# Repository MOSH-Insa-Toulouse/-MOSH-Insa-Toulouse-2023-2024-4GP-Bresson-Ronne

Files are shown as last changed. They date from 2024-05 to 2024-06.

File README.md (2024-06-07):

# -MOSH-Insa-Toulouse-2023-2024-4GP-Bresson-Ronne

Projet 4GP du capteur au banc de test en open source hardware
---
## Sommaire
  - [1) Contexte](#1-contexte)
  - [2) L'électronique Analogique](#2-L'électroniqueAnalogique)
  - [3) Kicad](#3-kicad)
  - [4) Le code Arduino](#4-lecodeArduino)
  - [5) L'application Bluetooth ](#5-l'appli)
  - [6) La DataSheet ](#6-data)
---

## 1) Contexte
Dans le cadre de l'UE "Du capteur au banc de test en Open Source Hardware", nous avons été amenés à réaliser un capteur de déformation low-tech à base de graphite. Le fonctionnement de ce capteur repose sur la variation de résistance engendrée par la déformation du matériau. La physique sous-jacente à cette variation de résistance provient du déplacement des électrons par effet tunnel entre les nanoparticules de graphite. Lorsqu'une contrainte mécanique est appliquée, la distance entre les nanoparticules varie, ce qui modifie la conductivité du graphite. Cette modification entraîne ainsi une variation de la résistance du capteur.<br>
Ce capteur est ensuite connnecté à un arduino. Divers élements sont ajoutés à l'Arduino, un capeteur flex sensor industriel que l'on comparera à notre capteur LowTech maison, un écran Oled pour pouvoir afficher nos résultats et un encodeur rotatoire qui permet de se déplacer sur les menus de l'écran Oled. Un module bluetooth est aussi implémenté en vue de créer une application android pour visualiser nos données. 

<p align="center">
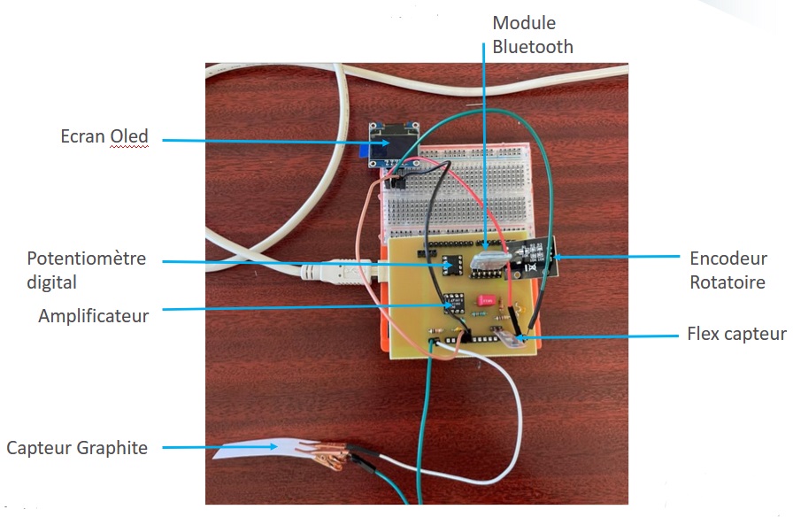
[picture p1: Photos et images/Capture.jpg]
Photo de l'installation
  
  <br>
  <i>Photo de l'installation</i>
</p>

## 2) L'électronique Analogique
Une partie importante de la chaîne d’acquisition pour notre capteur réside dans le
conditionnement du signal délivré par le capteur, c’est-à-dire l’amplifier et le filtrer
pour pouvoir l’exploiter. Afin d’utiliser les capacités de la carte Arduino au maximum
(en pleine échelle), le gain du circuit d’amplification est variable grâce à la résistance
R2, ajustée par un potentiomètre digital.<br>
Le filtrage est effectué à plusieurs niveaux (avant et après amplification). Il y a donc 3
étages, chacun avec une fréquence de coupure différente, pour limiter le bruit au
maximum. Le circuit est modélisé dans LTSpice, afin d’effectuer des simulations. Il
faut noter qu’ici on peut se permettre d’avoir un filtrage fort à des fréquences très
faibles car à priori notre capteur ne sera pas utilisé à plus qu’environ 1Hz. Les
résultats obtenus par les simulations et un exemple de simulation (Diagramme de
Bode pour un étage sont présentés sur les figures suivantes. Le circuit LTSpice est à
trouver dans le dossier « électronique analogique ».

<p align="center">
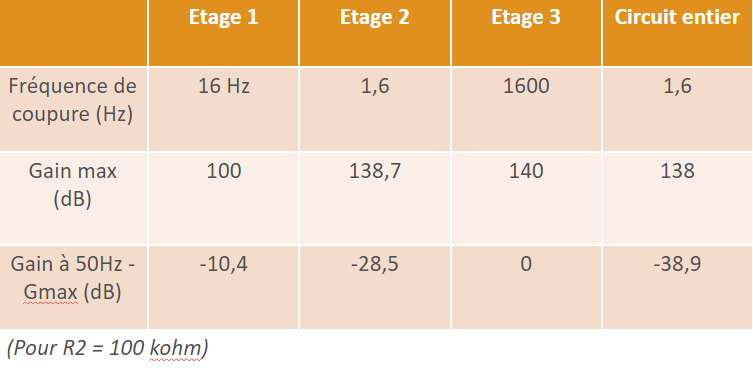
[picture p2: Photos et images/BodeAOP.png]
Caractéristiques de l'AOP
  
  <br>
  <i>Caractéristiques de l'AOP</i>
</p>

<p align="center">
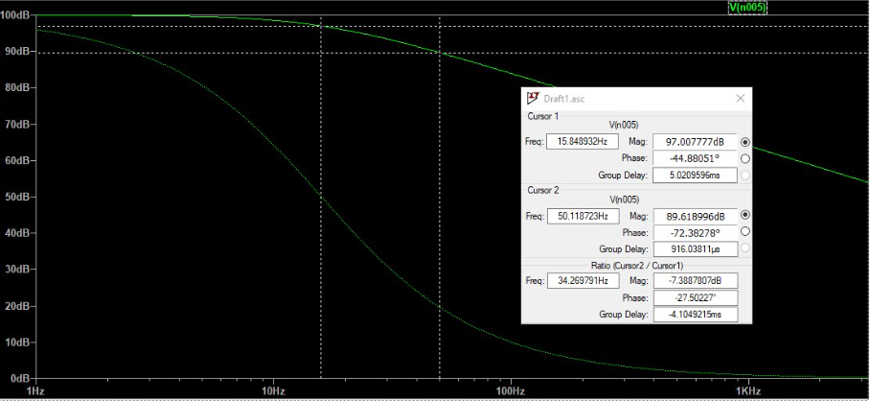
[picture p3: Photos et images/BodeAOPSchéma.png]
Diagramme de Bode du premier étage de l'AOP
  
  <br>
  <i>Diagramme de Bode du premier étage de l'AOP</i>
</p>

## 3) Kicad
Afin de réaliser en pratique le circuit modélisé dans LTSpice, ainsi qu’ajouter tous les
composants liés à notre chaîne d’acquisition et aux capteurs, le logiciel KiCad est
utilisé. Il permet à partir d’un schéma électrique, créé dans un premier temps, et de
l’ajout des empreintes et modèles 3D des différents composants, de modéliser le
PCB et ses pistes électroniques, et d’en obtenir un modèle 3D. Ces documents sont
disponibles dans le dossier « KiCad ». Avec l’aide de Catherine Crouzet, nous avons
ensuite pu fabriquer notre PCB y souder les composants pour tester toute notre
chaîne d’acquisition, qui s’est avérée fonctionnelle directement.

<p align="center">
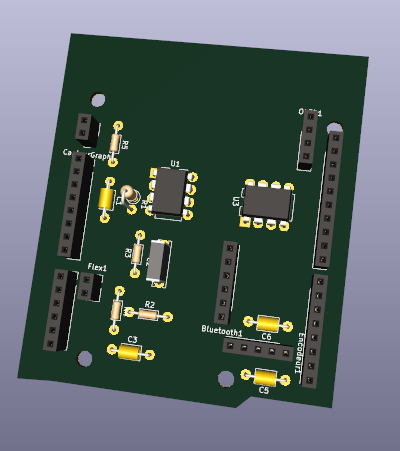
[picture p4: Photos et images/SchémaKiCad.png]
Schéma du PCB réalisé sur KiCad
  
  <br>
  <i>Schéma du PCB réalisé sur KiCad</i>
</p>

## 4) Le code Arduino

Un code Arduino est implémenté sur un ArduinoUno. Le code permet d'afficher les valeurs de résistance sur l'écran oled et de choisir quel capteur est affiché via un encodeur rotatoire. Les valeurs de résitances sont aussi disponibles sur le serialmonitor ainsi que sur le téléphone. 

## 5) Lapplication 
L’application Android, créée avec le MIT App Inventor, permet de dialoguer via Bluetooth
(bouton de connexion à activer) avec la carte Arduino pour obtenir les valeurs de
résistance/angle fournies par le capteur. L’utilisateur peut choisir un nombre de mesures à
effectuer, le moment pour les lancer, puis ces mesures sont affichées en live sur un
indicateur numérique, un graphique, et exportées dans un tableur afin de les exploiter au
mieux. Un fichier APK est téléchargeable dans le dossier « Application Android »

<p align="center">
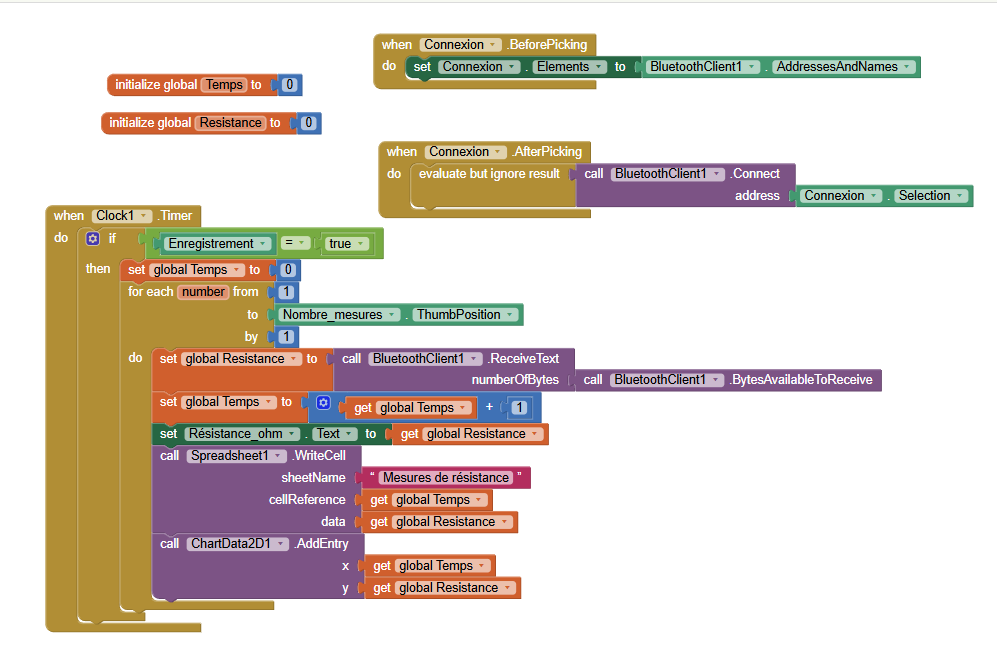
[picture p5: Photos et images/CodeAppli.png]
Schéma de l'application Android
  
  <br>
  <i>Schéma de l'application Android</i>
</p>

## 6) La DataSheet 
La data sheet du capteur est disponible  [ici](https://github.com/MOSH-Insa-Toulouse/2023-2024-4GP-Bresson-Ronne/blob/main/DataSheet/datasheetCapteurBressonRonne.pdf).

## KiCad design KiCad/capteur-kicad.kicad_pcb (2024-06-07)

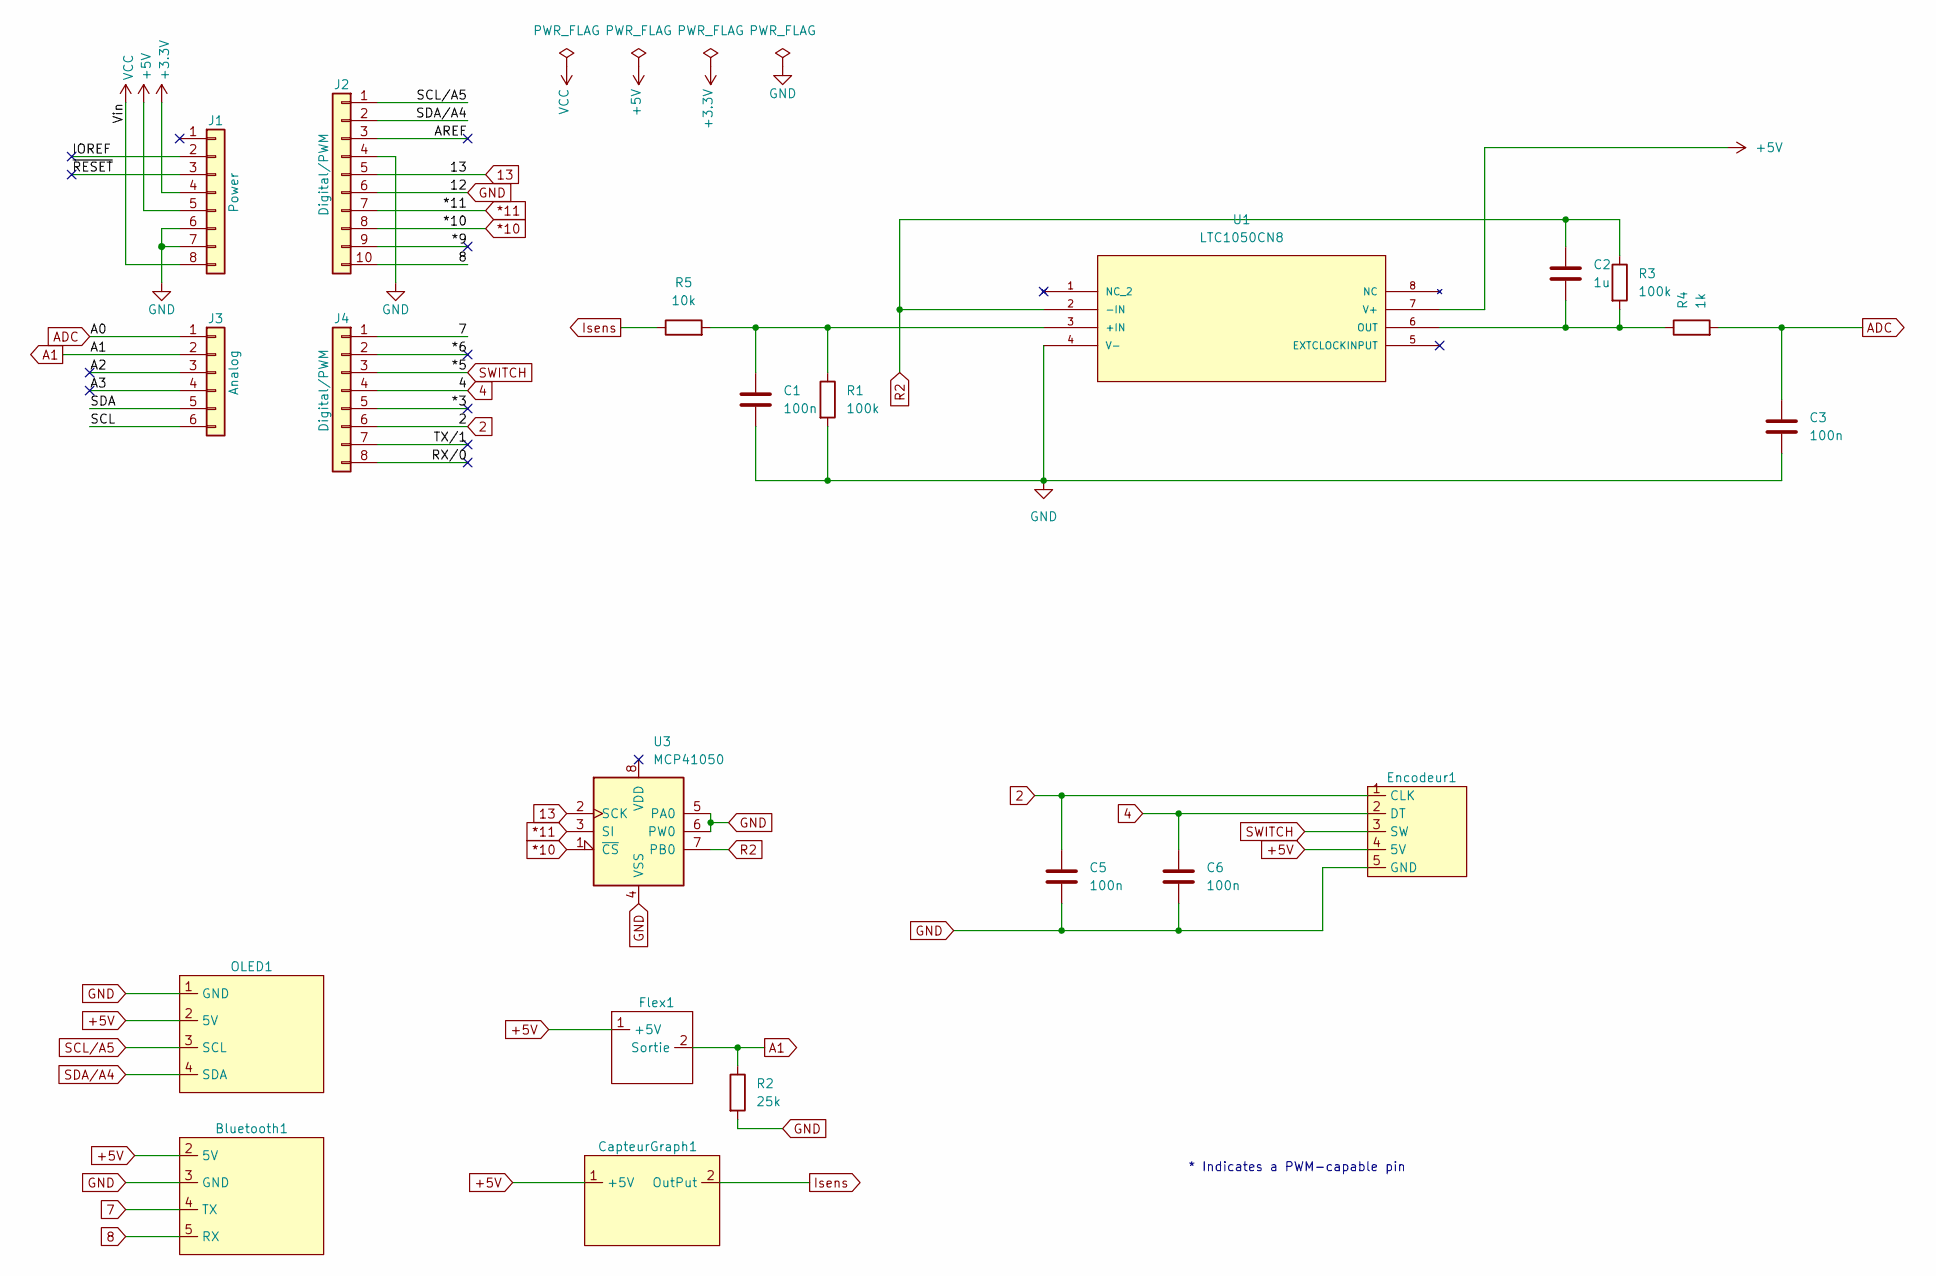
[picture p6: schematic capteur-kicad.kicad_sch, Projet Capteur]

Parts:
Bluetooth1: PinSocket_1x06_P2.54mm_Vertical
C1, C3, C5, C6: 100n; C_Axial_L3.8mm_D2.6mm_P7.50mm_Horizontal
C2: 1u; C_Rect_L9.0mm_W2.5mm_P7.50mm_MKT
CapteurGraph1: PinSocket_1x02_P2.54mm_Vertical
Encodeur1: PinSocket_1x05_P2.54mm_Vertical
Flex1: PinSocket_1x02_P2.54mm_Vertical
J1: Power; PinSocket_1x08_P2.54mm_Vertical
J2: Digital/PWM; PinSocket_1x10_P2.54mm_Vertical
J3: Analog; PinSocket_1x06_P2.54mm_Vertical
J4: Digital/PWM; PinSocket_1x08_P2.54mm_Vertical
OLED1: PinSocket_1x04_P2.54mm_Vertical
R1: 100k; R_Axial_DIN0207_L6.3mm_D2.5mm_P2.54mm_Vertical
R2: 25k; R_Axial_DIN0204_L3.6mm_D1.6mm_P7.62mm_Horizontal
R3: 100k; R_Axial_DIN0204_L3.6mm_D1.6mm_P7.62mm_Horizontal
R4: 1k; R_Axial_DIN0204_L3.6mm_D1.6mm_P7.62mm_Horizontal
R5: 10k; R_Axial_DIN0204_L3.6mm_D1.6mm_P7.62mm_Horizontal
U1: LTC1050CN8; DIP-8_W7.62mm; MANUFACTURER_PART_NUMBER ltc1050cn8
U3: MCP41050; DIP-8_W7.62mm

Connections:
2: C5.1, Encodeur1.1 (CLK), J4.6
4: C6.1, Encodeur1.2 (DT), J4.4
7: Bluetooth1.4 (TX), J4.1
8: Bluetooth1.5 (RX), J2.10
13: J2.5, U3.2 (SCK)
*10: J2.8, U3.1 (~CS)
*11: J2.7, U3.3 (SI)
+3V3: J1.4
+5V: Bluetooth1.2 (5V), CapteurGraph1.1 (+5V), Encodeur1.4 (5V), Flex1.1 (+5V), J1.5, OLED1.2 (5V), U1.7 (V+)
/*3: J4.5
/*6: J4.2
/*9: J2.9
/A2: J3.3
/A3: J3.4
/AREF: J2.3
/IOREF: J1.2
/RX/0: J4.8
/SCL: J3.6
/SDA: J3.5
/TX/1: J4.7
/~RESET: J1.3
A1: Flex1.2 (Sortie), J3.2, R2.1
ADC: C3.1, J3.1, R4.2
GND: Bluetooth1.3 (GND), C1.2, C3.2, C5.2, C6.2, Encodeur1.5 (GND), J1.6, J1.7, J2.4, J2.6, OLED1.1 (GND), R1.2, R2.2, U1.4 (V-), U3.4 (VSS), U3.5 (PA0), U3.6 (PW0)
Isens: CapteurGraph1.2 (OutPut), R5.1
unnamed: C1.1, R1.1, R5.2, U1.3 (+IN)
unnamed: C2.2, R3.2, R4.1, U1.6 (OUT)
R2: C2.1, R3.1, U1.2 (-IN), U3.7 (PB0)
SCL/A5: J2.1, OLED1.3 (SCL)
SDA/A4: J2.2, OLED1.4 (SDA)
SWITCH: Encodeur1.3 (SW), J4.3
VCC: J1.8

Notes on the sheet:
* Indicates a PWM-capable pin

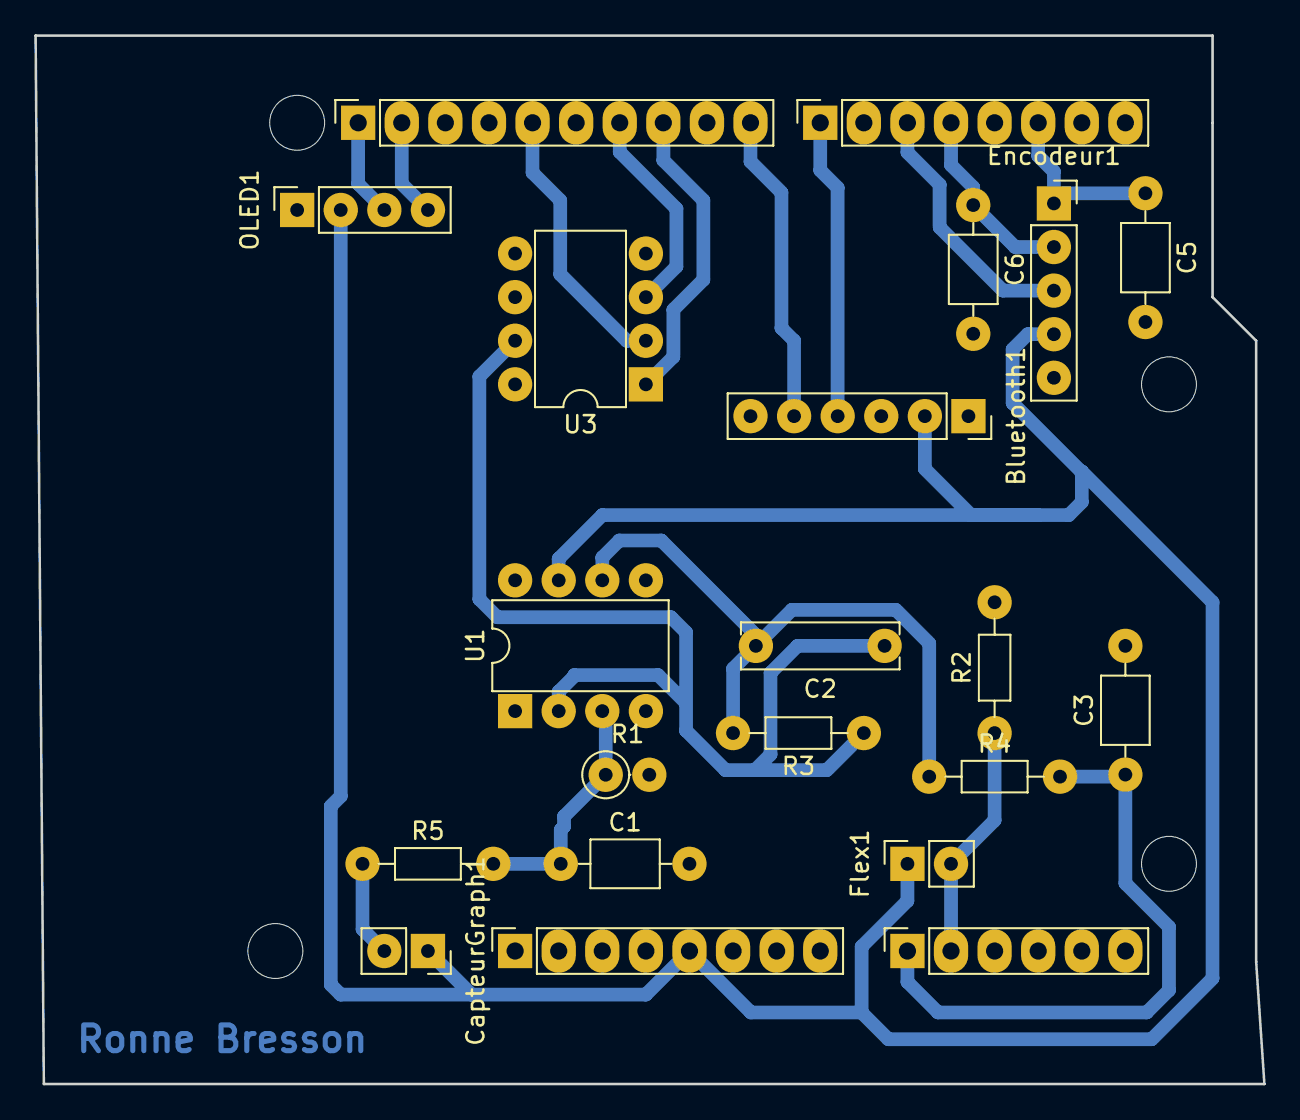
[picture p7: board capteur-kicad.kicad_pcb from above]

Board: 2 copper layers, 71.6 x 61.1 mm, 25 parts (0 on the bottom side), 18 nets.

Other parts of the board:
MH1, MH2, MH3, MH4: MountingHole_3.2mm

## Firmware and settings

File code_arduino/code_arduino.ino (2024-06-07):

//oled
#include <Adafruit_SSD1306.h>
#include <SPI.h>
#include <Adafruit_GFX.h>
#include <SoftwareSerial.h>
#define nombreDePixelsEnLargeur 128         // Taille de l'écran OLED, en pixel, au niveau de sa largeur
#define nombreDePixelsEnHauteur 64          // Taille de l'écran OLED, en pixel, au niveau de sa hauteur
#define brocheResetOLED         -1          // Reset de l'OLED partagé avec l'Arduino (d'où la valeur à -1, et non un numéro de pin)
#define adresseI2CecranOLED     0x3C        // Adresse de "mon" écran OLED sur le bus i2c (généralement égal à 0x3C ou 0x3D)
#define DEBUG
#define MCP_NOP 0b00000000
#define MCP_WRITE 0b00010001
#define MCP_SHTDWN 0b00100001
//#include <SoftwareSerial.h>
#define baudrate 9600
#include <Adafruit_SSD1306.h>
#include <SPI.h>
#define SCREEN_WIDTH 128
#define SCREEN_HEIGHT 64
#define OLED_RESET -1
#define OLED_ADDRESS 0x3C

#define Switch 5 // Switch connection if available

const int ssMCPin = 10; // Define the slave select for the digital pot

#define WAIT_DELAY 5000

//Flex sensor
Adafruit_SSD1306 display(SCREEN_WIDTH, SCREEN_HEIGHT, &Wire, OLED_RESET);
const int flexPin = A1;      // Pin connected to voltage divider output
const int analogInPin = A0;
const int analogOutPin = 9;
float Rflex=0;
float Resistance=0;
int VCC=5;
int R_DIV=24000;
int flatResistance=25000;
int bendResistance=100000;
float sensorValue;
float outputValue;
float valresflex;
char buffer[10];
char resflex[15];
char resgraph[15];

// Constantes
int lastStateCLK;
int lastStateDT;
int stateCLK;
int stateDT;

//bouton 


#include <SPI.h>

int res = 128;  // Valeur de résistance par défaut
const byte csPin = 10;  // Broche de sélection du MCP42100
const int maxPositions = 256;  // Nombre de positions possibles pour le curseur (de 0 à 255 = 256 positions)
const long rAB = 50000;  // Résistance entre les bornes A et B du potentiomètre 100k (92500 ohms pour ajustement au multimètre)
const byte rWiper = 125;  // Résistance du curseur du potentiomètre (125 ohms)
const byte pot0 = 0x11;  // Adresse du potentiomètre 0
const byte pot0Shutdown = 0x21;  // Adresse pour éteindre le potentiomètre 0

// Définition des broches pour l'encodeur rotatif
const int CLK = 6;  // Broche CLK de l'encodeur rotatif
const int DT = 4;   // Broche DT de l'encodeur rotatif

// Variables pour suivre l'état de l'encodeur rotatif
int oldCLKState = HIGH;  // Ancien état de la broche CLK
int counter = 128;  // Compteur de position du curseur

// Fonction pour ajuster la position du curseur du potentiomètre
void setPotWiper(int addr, int pos) {
  pos = constrain(pos, 0, 255);  // Limiter la position du curseur entre 0 et 255
  digitalWrite(csPin, LOW);  // Sélectionner le MCP42100
  SPI.transfer(addr);  // Configurer le potentiomètre cible avec la position du curseur
  SPI.transfer(pos);
  digitalWrite(csPin, HIGH);  // Désélectionner le MCP42100

  // Calcul de la résistance entre le curseur et la borne B
  long resistanceWB = ((rAB * pos) / maxPositions) + rWiper;
  Serial.print("Position du curseur : ");
  Serial.println(pos);
  Serial.print("Résistance du potentiomètre digital est égale à: ");
  Serial.print(resistanceWB);
  Serial.println(" ohms");
}


void setup() {
  // initialize serial communication at 9600 bits per second:
  Serial.begin(9600);
  
  pinMode(csPin, OUTPUT);  // Configurer la broche de sélection comme sortie
  SPI.begin();
  digitalWrite(csPin, HIGH);  // Désélectionner par défaut le MCP42100

  // Configurer les broches de l'encodeur rotatif en entrée avec pull-up
  pinMode(CLK, INPUT_PULLUP);
  pinMode(DT, INPUT_PULLUP);
  attachInterrupt(0, doEncoder, RISING);
  if (!display.begin(SSD1306_SWITCHCAPVCC, OLED_ADDRESS))
    while (1);
  display.clearDisplay();
  display.setTextSize(2);
  display.setTextColor(SSD1306_WHITE);
 
}
// the loop routine runs over and over again forever:
void loop() { 
  display.clearDisplay();
  display.setCursor(0, 0);
  display.print("ValRes:    ");
  display.println(res);
  display.display();
  setPotWiper(pot0,res);                    // Arrêt du programme (boucle infinie) si échec d'initialisation
  int ADCflex = analogRead(flexPin);
  float Vflex = ADCflex * VCC / 1023.0;
  float Rflex = (R_DIV * (VCC / Vflex - 1.0));
  float angle = map(Rflex, flatResistance, bendResistance, 0, 90.0);
  float angle2= map(valresflex, 64000000,2500000, 0, 90.0);

  sensorValue = analogRead(analogInPin);
  // map it to the range of the analog out:
  outputValue = sensorValue*5/1023;
  valresflex=((101*100)*5/outputValue);

  // change the analog out value:
  analogWrite(analogOutPin, outputValue);

  // print the results to the Serial Monitor:
  Serial.println("Résitance du capteur Graphène=" + String(abs(valresflex)) + "kohms");
  Serial.println("Resistance du Flex Sensor : " + String(Rflex/1000) + " kohms");
  Serial.println("Angle du capteur graphite:" + String(angle2) + " degrés");
  Serial.println("Angle du flexsensor:" + String(angle) + " degrés");
  Serial.println();
  
 


  delay(1000);
}
 

void doEncoder(){
  

  if (digitalRead(DT)==LOW) {
    res++;
    
    }
    else if (digitalRead(DT)==HIGH){
      res--;
    }

}

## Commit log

2024-05-30 Create Code Arduino
2024-05-30 Create KiCad

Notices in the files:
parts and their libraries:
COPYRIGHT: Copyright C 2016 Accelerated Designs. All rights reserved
